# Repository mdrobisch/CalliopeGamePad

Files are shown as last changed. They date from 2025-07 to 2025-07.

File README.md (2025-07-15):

# CalliopeGamePad

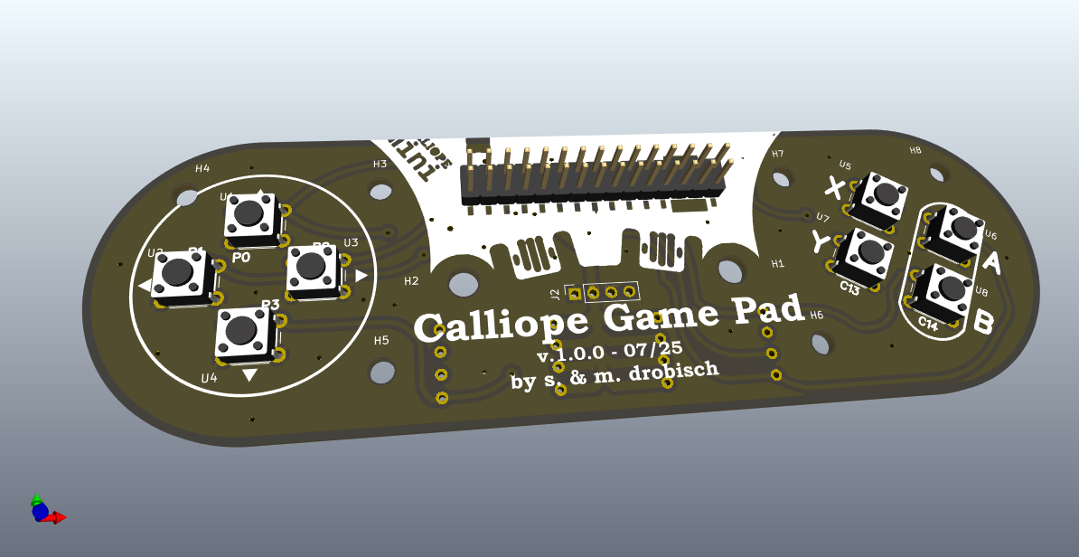
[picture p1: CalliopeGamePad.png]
CalliopeGamePad


The CalliopeGamePad adds a gamepad to the Calliope Mini V3 (https://calliope.cc/).
This project is a open source hardware project made with KiCAD (https://www.kicad.org/).
It is intended to be 100% compatible with the CallioGamer of M. Klein @ https://www.hackster.io/MKlein/calliogamer-f57906 . Thanks goes to M. Klein for his wonderful project and his software @ https://github.com/MKleinSB/pxt-calliogamer.

ATTENTION: Due to the connector the Calliope Game Pad Works **only** with Calliope Mini V3.

Here are some differeneces compared to the CallioGamer:

* The CallioGamer production files seems to be broken somehow (at least for my PCB fab of choice). Now you have the freedom to adjust for yours as well.
* Added some additional mounting holes. So you can add a solid body to the board (e.g., cardboard or 3d-print)
* Optional Pull-Up resistors are available. This can also be used for filtering of the buttons with additional capacitors. There is **no need** to solder this for a working gamepad.
* CalliopeGamePad is made in KiCAD 9 (instead of EasyEDA)

You can remix the project and adjust as you like. The hardware is licensed under Creative Commons (CC BY-SA). Please visit the projects of M.Klein and have fun.

## Build your own

Almost all of the big PCB Fabs are able to handle.kicad_pcb files directly. Just upload and let them produce your Calliope Game Pad. In addition you find the gerber fabrication files in the `gerber` directory.

## Software

Please follow the instruction at https://www.hackster.io/MKlein/calliogamer-f57906 . 

You can find the source code of the CallioGamer firmware at https://github.com/MKleinSB/pxt-calliogamer .

## Legal statement

Please read the DISCLAIMER and the LICENSE.

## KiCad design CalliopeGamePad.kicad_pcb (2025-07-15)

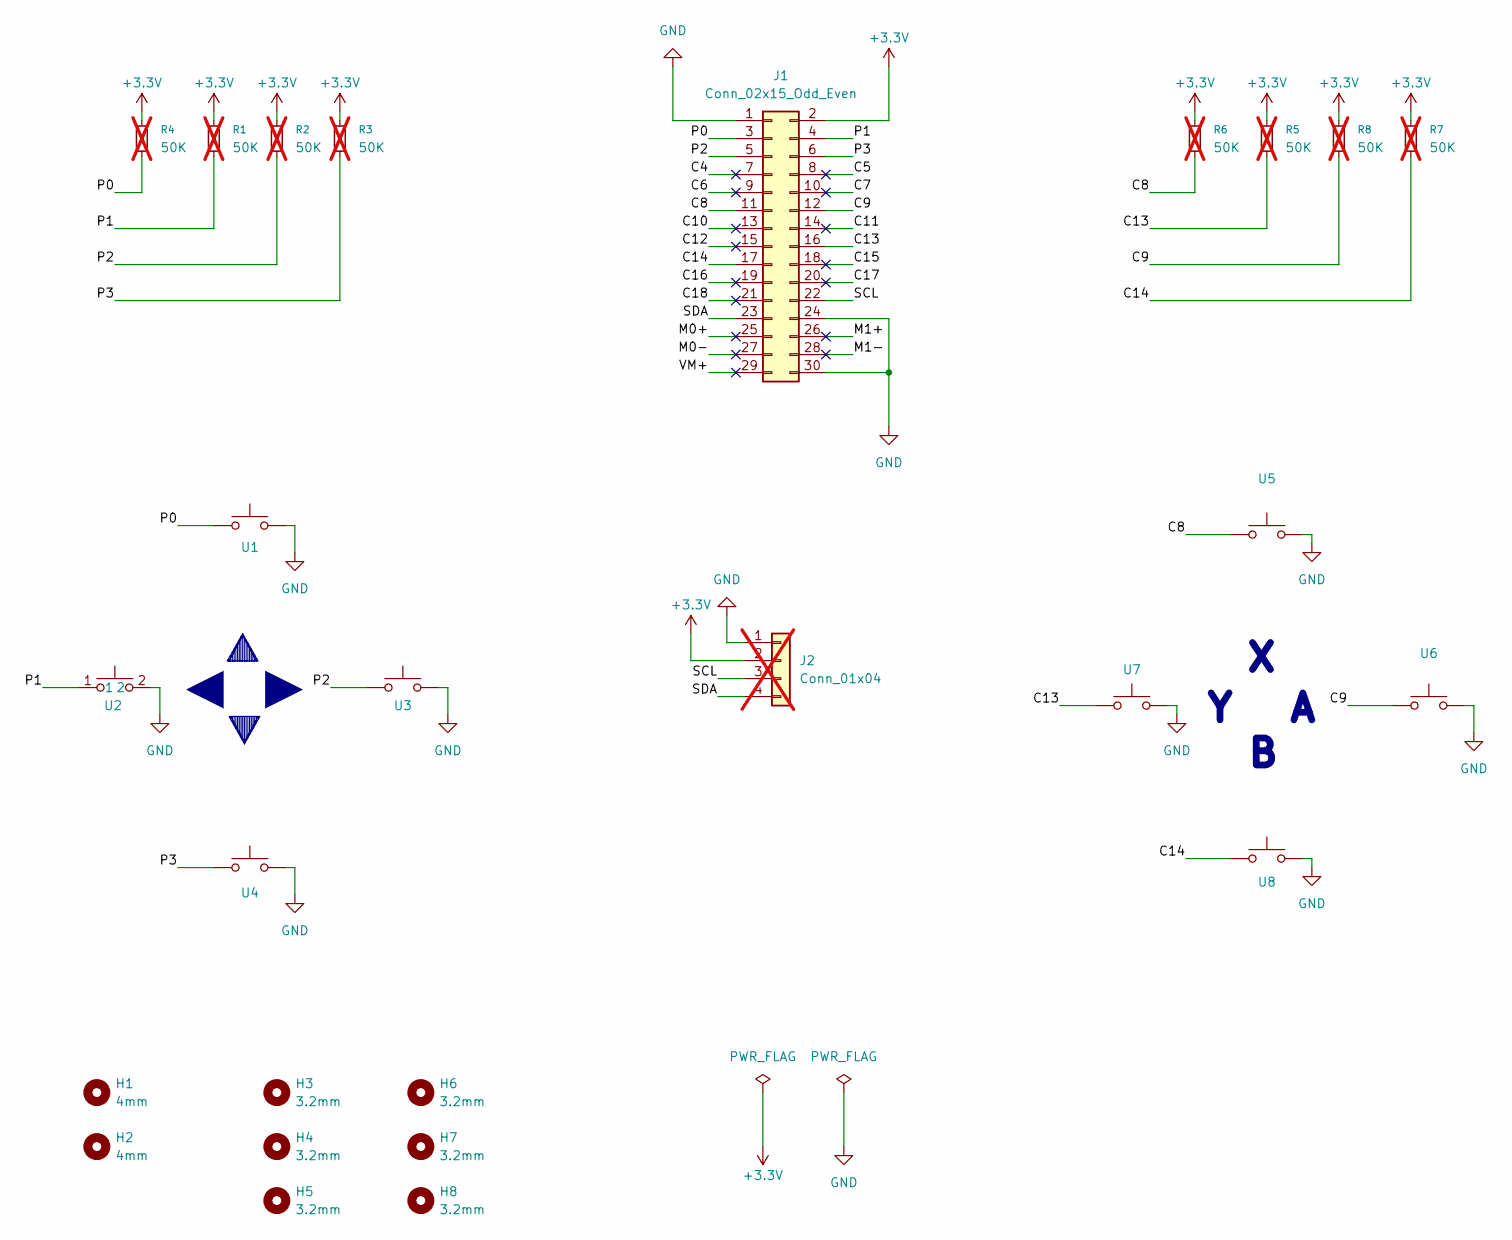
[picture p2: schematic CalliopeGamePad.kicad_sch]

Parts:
H1, H2: 4mm; MountingHole_4mm
H3, H4, H5, H6, H7, H8: 3.2mm; MountingHole_3.2mm_M3_DIN965
J1: Conn_02x15_Odd_Even; PinSocket_2x15_P2.54mm_Vertical
J2: Conn_01x04; PinSocket_1x04_P2.54mm_Vertical; not fitted
R1, R2, R3, R4, R5, R6, R7, R8: 50K; R_Axial_DIN0207_L6.3mm_D2.5mm_P15.24mm_Horizontal; not fitted
U1, U2, U3, U4, U5, U6, U7, U8: SW_MEC_5E; SW_PUSH_6mm

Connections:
+3.3V: J1.2, J2.2, R1.1, R2.1, R3.1, R4.1, R5.1, R6.1, R7.1, R8.1
/C4: J1.7
/C5: J1.8
/C6: J1.9
/C7: J1.10
/C8: J1.11, R6.2, U5.1
/C9: J1.12, R8.2, U6.1
/C10: J1.13
/C11: J1.14
/C12: J1.15
/C13: J1.16, R5.2, U7.1
/C14: J1.17, R7.2, U8.1
/C15: J1.18
/C16: J1.19
/C17: J1.20
/C18: J1.21
/M0+: J1.25
/M0-: J1.27
/M1+: J1.26
/M1-: J1.28
/P0: J1.3, R4.2, U1.1
/P1: J1.4, R1.2, U2.1
/P2: J1.5, R2.2, U3.1
/P3: J1.6, R3.2, U4.1
/SCL: J1.22, J2.3
/SDA: J1.23, J2.4
/VM+: J1.29
GND: J1.1, J1.24, J1.30, J2.1, U1.2, U2.2, U3.2, U4.2, U5.2, U6.2, U7.2, U8.2

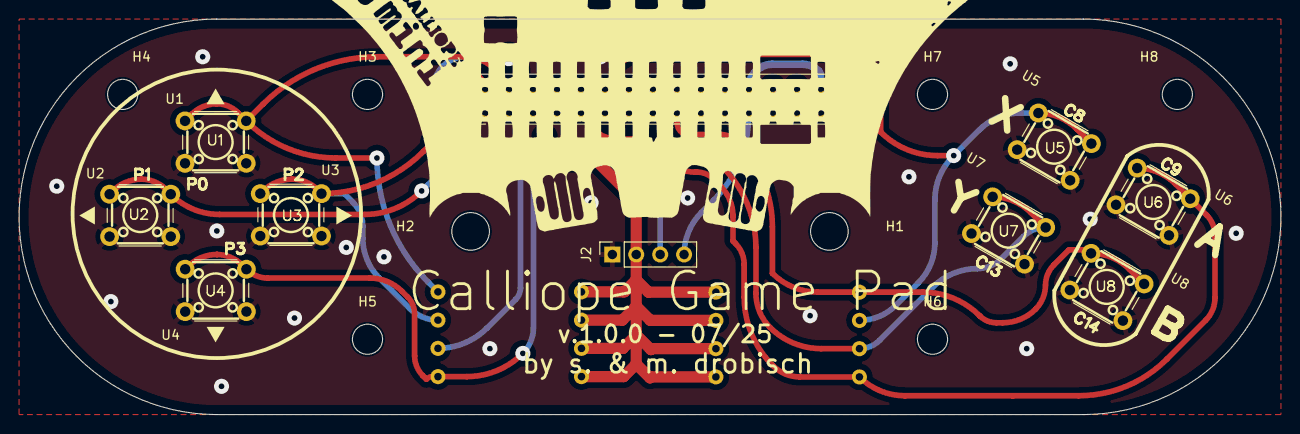
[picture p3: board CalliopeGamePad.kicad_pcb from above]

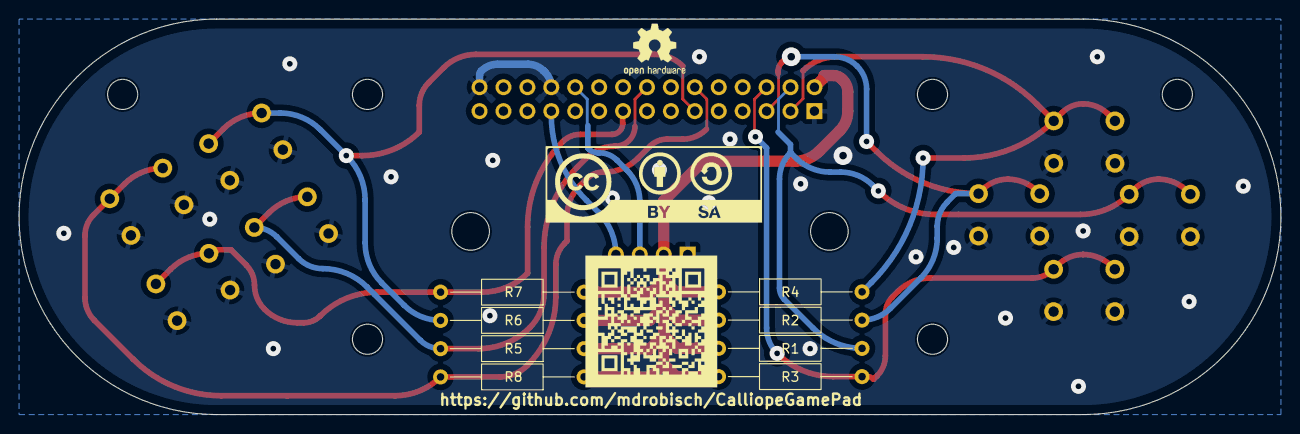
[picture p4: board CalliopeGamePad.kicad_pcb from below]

Board: 2 copper layers, 134.0 x 42.0 mm, 26 parts (8 on the bottom side), 12 nets.

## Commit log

2025-07-14 ADD project
    [CalliopeGamePad.kicad_pcb, CalliopeGamePad.kicad_sch]
2025-07-14 ADD gerber files
    [CalliopeGamePad-B_Cu.gbr, CalliopeGamePad-B_Mask.gbr, CalliopeGamePad-B_Paste.gbr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]
2025-07-15 MAKE the socket a pin header and reroute pin map
    [CalliopeGamePad.kicad_pcb]
2025-07-15 ADD a hint for using filter
2025-07-15 UPDATE socket footprint in kicad_sch
    [CalliopeGamePad.kicad_sch]
2025-07-15 UPDATE Gerber and Drill Files
    [CalliopeGamePad-B_Cu.gbr, CalliopeGamePad-B_Mask.gbr, CalliopeGamePad-B_Paste.gbr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]
